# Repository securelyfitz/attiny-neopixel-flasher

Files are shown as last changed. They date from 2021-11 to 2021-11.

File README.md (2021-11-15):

# attiny-neopixel-flasher
quick and dirty lipo + neopixel flasher making use of parts on hand

## Circuit
Power provided by a lipo battery using a 1mm pitch 4-pin jst connector.
Power connects to the ATTINY85 and neopixels
Button connects to reset - the ATTINY keeps track of which pattern it's on in eeprom, and plays the next one at reset.

## Power saving hack
WS2182's consume 1mA when off, discharging the 1000mAh pack in a day, so now I power them with ATTINY GPIO pins. ATTINY GPIO pins provide max 40mA each 60mA combined, so I scratched off the trace and soldered a bodge wire to two pins (2+3) and the vcc pin of the neopixel ring

## PCB
Using all built-in footprints, manually placed 1x1 headers for connection to the 16-neopixel rings i have on hand. Optimized for milling with fat bits, so i removed pins 2,3,6,7 from the attiny footprint. Still need to use a V bit to get the space between the power connector pins but the rest is 1/32" flat end. Sized to match the batteries i had lying around.

## Software
Based on adafruit's neopixel strandtest with minor additions:
* use EEPROM to store/load state on reset
* choose patterns based on switch statement of eeprom state
* looped patters to each last ~60s
* use sleep.h features to go to sleep after pattern runs through
* toggle pins 3&4 to provide power for neopixels
* added rainbowall pattern to do same rainbow color to all leds
Used Arduino IDE with https://github.com/SpenceKonde/ATTinyCore for attiny85 support.

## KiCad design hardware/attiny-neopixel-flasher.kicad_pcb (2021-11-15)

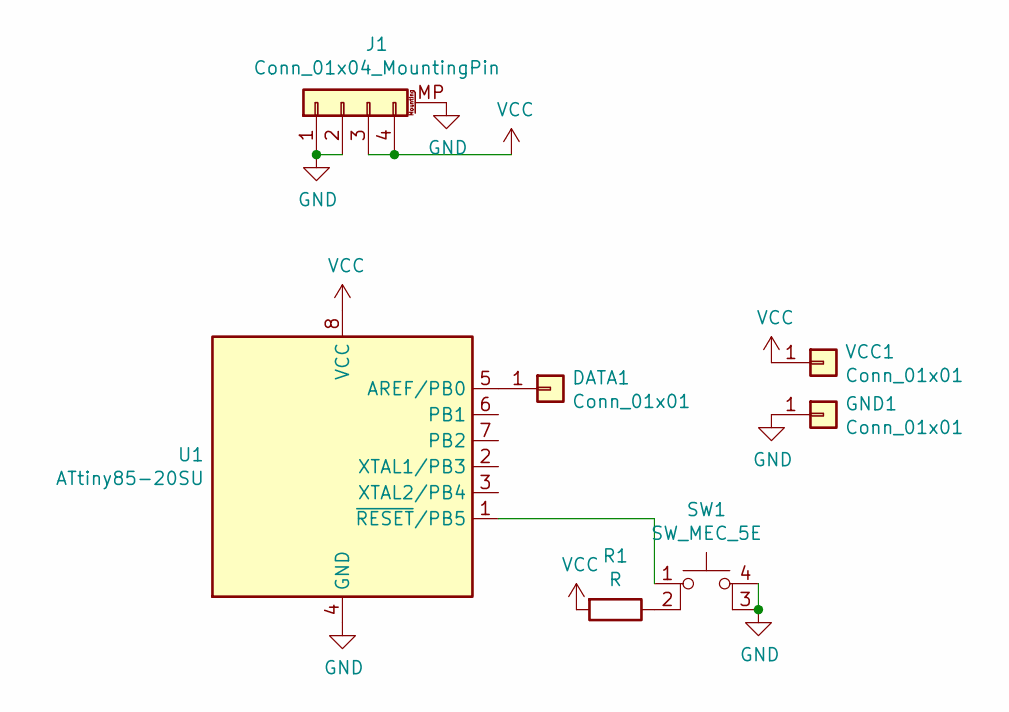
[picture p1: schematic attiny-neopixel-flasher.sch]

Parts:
DATA1: Conn_01x01; PinHeader_1x01_P2.54mm_Vertical
GND1: Conn_01x01; PinHeader_1x01_P2.54mm_Vertical
J1: Conn_01x04_MountingPin; JST_SH_SM04B-SRSS-TB_1x04-1MP_P1.00mm_Horizontal
R1: R; R_1206_3216Metric
SW1: SW_MEC_5E; SW_TH_Tactile_Omron_B3F-10xx
U1: ATtiny85-20SU; SOIJ-8_5.3x5.3mm_P1.27mm
VCC1: Conn_01x01; PinHeader_1x01_P2.54mm_Vertical

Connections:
GND: GND1.1, J1.1, J1.2, J1.MP (MountPin), SW1.3 (K), SW1.4 (A), U1.4 (GND)
unnamed: DATA1.1, U1.5 (AREF/PB0)
unnamed: R1.1, SW1.2
unnamed: SW1.1, U1.1 (~RESET~/PB5)
VCC: J1.3, J1.4, R1.2, U1.8 (VCC), VCC1.1

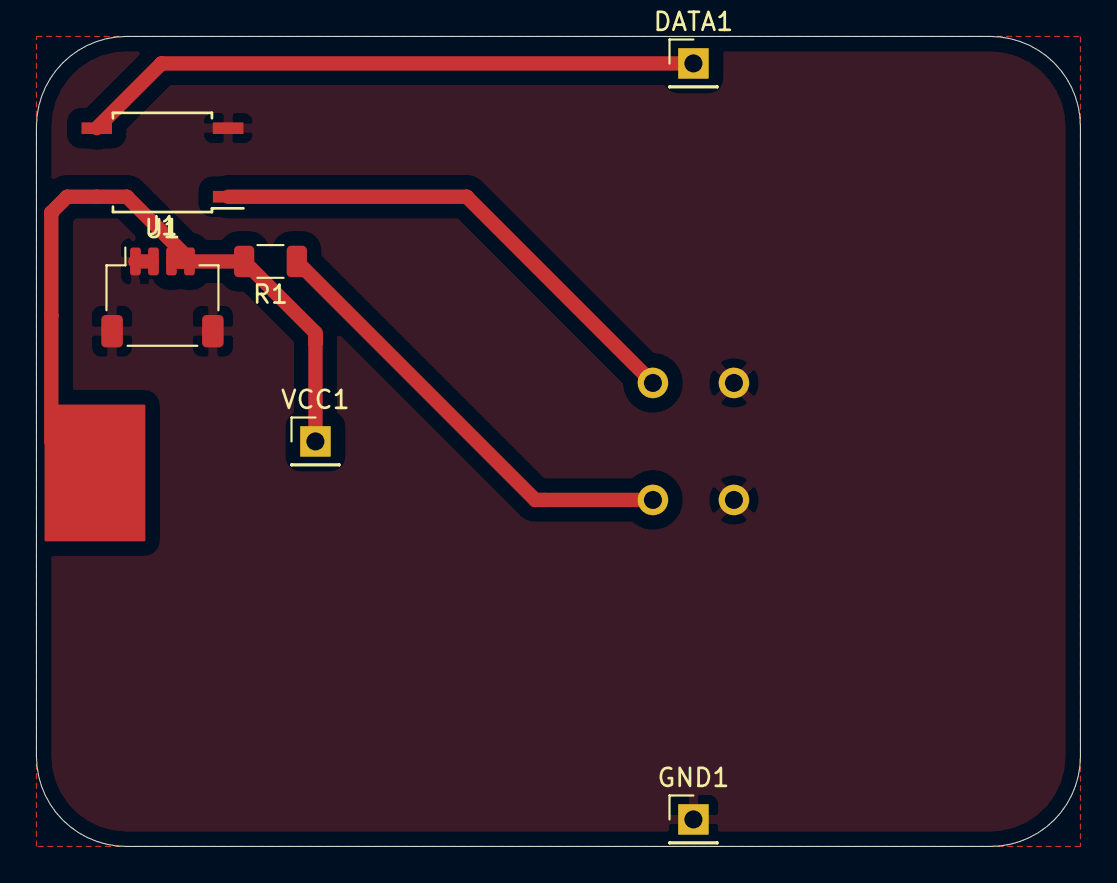
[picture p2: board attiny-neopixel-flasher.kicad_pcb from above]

Board: 2 copper layers, 58.0 x 45.0 mm, 7 parts (1 on the bottom side), 5 nets.

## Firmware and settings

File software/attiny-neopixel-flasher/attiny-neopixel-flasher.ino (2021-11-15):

// A basic everyday NeoPixel strip test program.

// NEOPIXEL BEST PRACTICES for most reliable operation:
// - Add 1000 uF CAPACITOR between NeoPixel strip's + and - connections.
// - MINIMIZE WIRING LENGTH between microcontroller board and first pixel.
// - NeoPixel strip's DATA-IN should pass through a 300-500 OHM RESISTOR.
// - AVOID connecting NeoPixels on a LIVE CIRCUIT. If you must, ALWAYS
//   connect GROUND (-) first, then +, then data.
// - When using a 3.3V microcontroller with a 5V-powered NeoPixel strip,
//   a LOGIC-LEVEL CONVERTER on the data line is STRONGLY RECOMMENDED.
// (Skipping these may work OK on your workbench but can fail in the field)

#include <Adafruit_NeoPixel.h>
#include <EEPROM.h>
#define EEADDR 0
#include <avr/sleep.h>

// Routines to set and claer bits (used in the sleep code)
#ifndef cbi
#define cbi(sfr, bit) (_SFR_BYTE(sfr) &= ~_BV(bit))
#endif
#ifndef sbi
#define sbi(sfr, bit) (_SFR_BYTE(sfr) |= _BV(bit))
#endif


#ifdef __AVR__
#include <avr/power.h> // Required for 16 MHz Adafruit Trinket
#endif

// Which pin on the Arduino is connected to the NeoPixels?
// On a Trinket or Gemma we suggest changing this to 1:
#define LED_PIN    0

// How many NeoPixels are attached to the Arduino?
#define LED_COUNT 16

// Declare our NeoPixel strip object:
Adafruit_NeoPixel strip(LED_COUNT, LED_PIN, NEO_GRB + NEO_KHZ800);
// Argument 1 = Number of pixels in NeoPixel strip
// Argument 2 = Arduino pin number (most are valid)
// Argument 3 = Pixel type flags, add together as needed:
//   NEO_KHZ800  800 KHz bitstream (most NeoPixel products w/WS2812 LEDs)
//   NEO_KHZ400  400 KHz (classic 'v1' (not v2) FLORA pixels, WS2811 drivers)
//   NEO_GRB     Pixels are wired for GRB bitstream (most NeoPixel products)
//   NEO_RGB     Pixels are wired for RGB bitstream (v1 FLORA pixels, not v2)
//   NEO_RGBW    Pixels are wired for RGBW bitstream (NeoPixel RGBW products)


// setup() function -- runs once at startup --------------------------------

void setup() {
  // These lines are specifically to support the Adafruit Trinket 5V 16 MHz.
  // Any other board, you can remove this part (but no harm leaving it):
#if defined(__AVR_ATtiny85__) && (F_CPU == 16000000)
  clock_prescale_set(clock_div_1);
#endif
  // END of Trinket-specific code.

  pinMode(3,OUTPUT);  //power on to neopixel supply
  pinMode(4,OUTPUT);  // 40ma max each
  digitalWrite(3,HIGH);  // 60ma max combined
  digitalWrite(4,HIGH);  // so short 3&4 and keep brightness low

  strip.begin();           // INITIALIZE NeoPixel strip object (REQUIRED)
  strip.show();            // Turn OFF all pixels ASAP
  strip.setBrightness(50); // Set BRIGHTNESS to about 1/5 (max = 255)

  EEPROM.write(EEADDR, (EEPROM.read(EEADDR) + 1) % 9);
}


// loop() function -- runs repeatedly as long as board is on ---------------

void loop() {
  int tick = 1000 / LED_COUNT; //num of ms per LED so full string takes 1s
  switch (EEPROM.read(EEADDR)) {
    case 0: //white loop then stay on
      colorWipe(strip.Color(127,  127,  127), tick); // White
      delay(60000);
      break;
    case 1: // loop through colors for 15s
      for (int x = 0; x < 20; x++) {
        colorWipe(strip.Color(255,   0,   0), tick); // Red
        colorWipe(strip.Color(  0, 255,   0), tick); // Green
        colorWipe(strip.Color(  0,   0, 255), tick); // Blue
      }
      break;
    case 2:
      for (int x = 0; x < 40; x++) {
        theaterChase(strip.Color(127,   0,   0), tick); // Red, half brightness
      }
      break;
    case 3:
      for (int x = 0; x < 40; x++) {
        theaterChase(strip.Color(0,   127,   0), tick); // green, half brightness
      }
      break;
    case 4:
      for (int x = 0; x < 40; x++) {
        theaterChase(strip.Color(  0,   0, 127), tick); // Blue, half brightness
      }
      break;
    case 5:
      for (int x = 0; x < 20; x++) {
        rainbow(10);             // Flowing rainbow cycle along the whole strip
      }
      break;
    case 6:
      for (int x = 0; x < 20; x++) {
        rainbowall(10);          // Flowing rainbow cycle along the whole strip
      }
      break;
    case 7:
      for (int x = 0; x < 20; x++) {
        theaterChaseRainbow(tick); // Rainbow-enhanced theaterChase variant
      }
      break;
    default:  //power off
      //      EEPROM.write(EEADDR, 0); //this will get wound back to here before powerdown, but back up to 0 at poweron
      //go to sleep in powerdown mode
      //should already be off, but just in case:
  
      strip.clear();            // Turn OFF all pixels ASAP
      strip.show();            // Turn OFF all pixels ASAP
      digitalWrite(3,LOW);
      digitalWrite(4,LOW);

      cbi(ADCSRA, ADEN);                   // switch Analog to Digitalconverter OFF
      set_sleep_mode(SLEEP_MODE_PWR_DOWN); // sleep mode is set here
      sleep_enable();
      sleep_mode();                        // System actually sleeps here
      sleep_disable();                     // System continues execution here when watchdog timed out
      sbi(ADCSRA, ADEN);                   // switch Analog to Digitalconverter ON
  }
  // if we get to the end, turn off prepare to repeat this pattern next time
  EEPROM.write(EEADDR, (9 + EEPROM.read(EEADDR) - 1) % 9);
  strip.clear();            // Turn OFF all pixels ASAP
  strip.show();            // Turn OFF all pixels ASAP
  
  digitalWrite(3,LOW);     /// power off to neopixel supply
  digitalWrite(4,LOW);

  //go to sleep in powerdown mode
  cbi(ADCSRA, ADEN);                   // switch Analog to Digitalconverter OFF
  set_sleep_mode(SLEEP_MODE_PWR_DOWN); // sleep mode is set here
  sleep_enable();
  sleep_mode();                        // System actually sleeps here
  sleep_disable();                     // System continues execution here when watchdog timed out
  sbi(ADCSRA, ADEN);                   // switch Analog to Digitalconverter ON
}


// Some functions of our own for creating animated effects -----------------

// Fill strip pixels one after another with a color. Strip is NOT cleared
// first; anything there will be covered pixel by pixel. Pass in color
// (as a single 'packed' 32-bit value, which you can get by calling
// strip.Color(red, green, blue) as shown in the loop() function above),
// and a delay time (in milliseconds) between pixels.
void colorWipe(uint32_t color, int wait) {
  for (int i = 0; i < strip.numPixels(); i++) { // For each pixel in strip...
    strip.setPixelColor(i, color);         //  Set pixel's color (in RAM)
    strip.show();                          //  Update strip to match
    delay(wait);                           //  Pause for a moment
  }
}

// Theater-marquee-style chasing lights. Pass in a color (32-bit value,
// a la strip.Color(r,g,b) as mentioned above), and a delay time (in ms)
// between frames.
void theaterChase(uint32_t color, int wait) {
  for (int a = 0; a < 10; a++) { // Repeat 10 times...
    for (int b = 0; b < 3; b++) { //  'b' counts from 0 to 2...
      strip.clear();         //   Set all pixels in RAM to 0 (off)
      // 'c' counts up from 'b' to end of strip in steps of 3...
      for (int c = b; c < strip.numPixels(); c += 3) {
        strip.setPixelColor(c, color); // Set pixel 'c' to value 'color'
      }
      strip.show(); // Update strip with new contents
      delay(wait);  // Pause for a moment
    }
  }
}

// Rainbow cycle along whole strip. Pass delay time (in ms) between frames.
void rainbow(int wait) {
  // Hue of first pixel runs 5 complete loops through the color wheel.
  // Color wheel has a range of 65536 but it's OK if we roll over, so
  // just count from 0 to 5*65536. Adding 256 to firstPixelHue each time
  // means we'll make 5*65536/256 = 1280 passes through this outer loop:
  for (long firstPixelHue = 0; firstPixelHue < 65536; firstPixelHue += 256) {
    for (int i = 0; i < strip.numPixels(); i++) { // For each pixel in strip...
      // Offset pixel hue by an amount to make one full revolution of the
      // color wheel (range of 65536) along the length of the strip
      // (strip.numPixels() steps):
      int pixelHue = firstPixelHue + (i * 65536L / strip.numPixels());
      // strip.ColorHSV() can take 1 or 3 arguments: a hue (0 to 65535) or
      // optionally add saturation and value (brightness) (each 0 to 255).
      // Here we're using just the single-argument hue variant. The result
      // is passed through strip.gamma32() to provide 'truer' colors
      // before assigning to each pixel:
      strip.setPixelColor(i, strip.gamma32(strip.ColorHSV(pixelHue)));
    }
    strip.show(); // Update strip with new contents
    delay(wait);  // Pause for a moment
  }
}

// Rainbow cycle along whole strip. Pass delay time (in ms) between frames.
void rainbowall(int wait) {
  // Hue of first pixel runs 5 complete loops through the color wheel.
  // Color wheel has a range of 65536 but it's OK if we roll over, so
  // just count from 0 to 5*65536. Adding 256 to firstPixelHue each time
  // means we'll make 5*65536/256 = 1280 passes through this outer loop:
  for (long firstPixelHue = 0; firstPixelHue < 65536; firstPixelHue += 256) {
    for (int i = 0; i < strip.numPixels(); i++) { // For each pixel in strip...
      // Offset pixel hue by an amount to make one full revolution of the
      // color wheel (range of 65536) along the length of the strip
      // (strip.numPixels() steps):
      //      int pixelHue = firstPixelHue + (i * 65536L / strip.numPixels());
      // strip.ColorHSV() can take 1 or 3 arguments: a hue (0 to 65535) or
      // optionally add saturation and value (brightness) (each 0 to 255).
      // Here we're using just the single-argument hue variant. The result
      // is passed through strip.gamma32() to provide 'truer' colors
      // before assigning to each pixel:
      strip.setPixelColor(i, strip.gamma32(strip.ColorHSV(firstPixelHue)));
    }
    strip.show(); // Update strip with new contents
    delay(wait);  // Pause for a moment
  }
}

// Rainbow-enhanced theater marquee. Pass delay time (in ms) between frames.
void theaterChaseRainbow(int wait) {
  int firstPixelHue = 0;     // First pixel starts at red (hue 0)
  for (int a = 0; a < 30; a++) { // Repeat 30 times...
    for (int b = 0; b < 3; b++) { //  'b' counts from 0 to 2...
      strip.clear();         //   Set all pixels in RAM to 0 (off)
      // 'c' counts up from 'b' to end of strip in increments of 3...
      for (int c = b; c < strip.numPixels(); c += 3) {
        // hue of pixel 'c' is offset by an amount to make one full
        // revolution of the color wheel (range 65536) along the length
        // of the strip (strip.numPixels() steps):
        int      hue   = firstPixelHue + c * 65536L / strip.numPixels();
        uint32_t color = strip.gamma32(strip.ColorHSV(hue)); // hue -> RGB
        strip.setPixelColor(c, color); // Set pixel 'c' to value 'color'
      }
      strip.show();                // Update strip with new contents
      delay(wait);                 // Pause for a moment
      firstPixelHue += 65536 / 90; // One cycle of color wheel over 90 frames
    }
  }
}

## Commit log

2021-11-15 adding arduino sketch based on adafruit's strandtest
2021-11-15 adding kicad recommended gitignore
2021-11-15 adding pcb
    [attiny-neopixel-flasher.kicad_pcb, attiny-neopixel-flasher.sch]
